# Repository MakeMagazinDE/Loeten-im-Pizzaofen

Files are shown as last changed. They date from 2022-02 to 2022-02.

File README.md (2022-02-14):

GitHub Logo

Maker Media GmbH

***

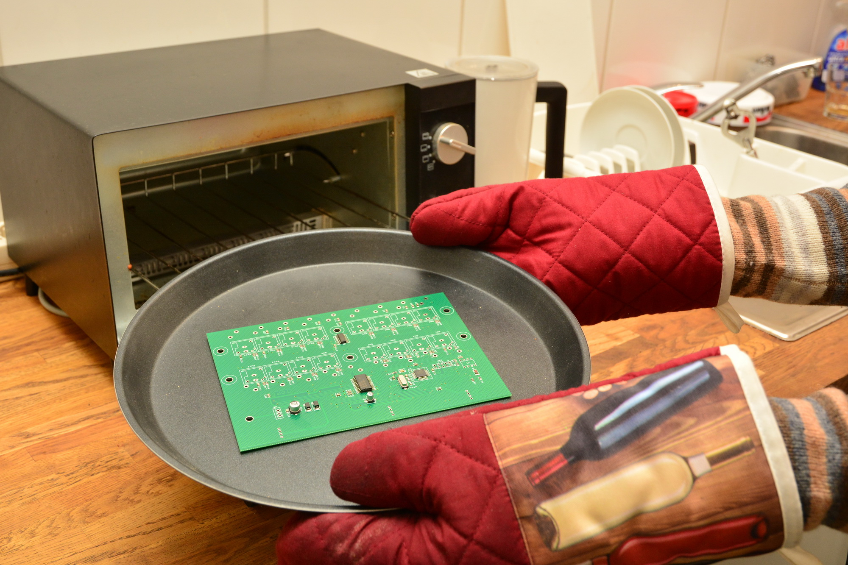
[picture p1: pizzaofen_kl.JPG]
 

# Löten im Pizzaofen

### Der Weg zur Platine, Teil 2

In unserem Artikel entsteht aus einem Pizza-Ofen eine praktische Reflow-Maschine für das Löten von SMD-Bauteilen mit WLAN-Fernsteuerung über den Browser.

**Nachtrag:** In der Schaltung ist R1 für normal helle LEDs zu hoch bemessen. Werte von 220 bis 470 Ohm sollten eine ausreichende Helligkeit erzielen.

### Verzeichnisse:

* **Beispielplatine** Die im Artikel angefertigte Platine, layoutet mit Sprint Layout (HPGL-Ausgabe)
* **reflow_oven** ESP32-Sourcen und Firmware
* **hpgl2gcode** Einfacher Konverter für HPGL-Dateien in G-Code, Sourcen und ausführbare EXE

Den vollständigen Artikel mit der Bauanleitung gibt es in der [Make-Ausgabe 1/22 ab Seite 86](https://www.heise.de/select/make/2022/1).

Teil 1 finden Sie in der [Make-Ausgabe 6/21 ab Seite 104](https://www.heise.de/select/make/2021/6/2130609051769976417).

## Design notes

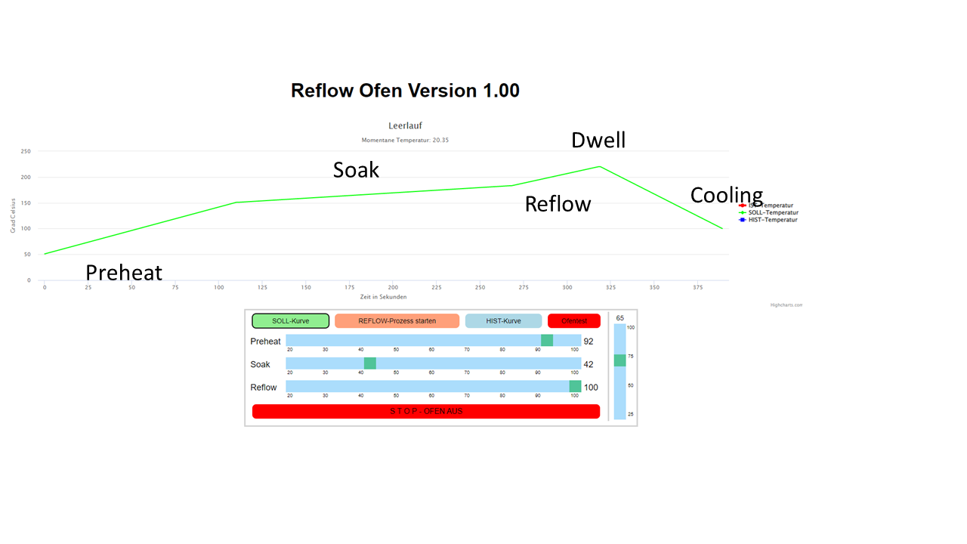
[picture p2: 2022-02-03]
reflow-profil.png

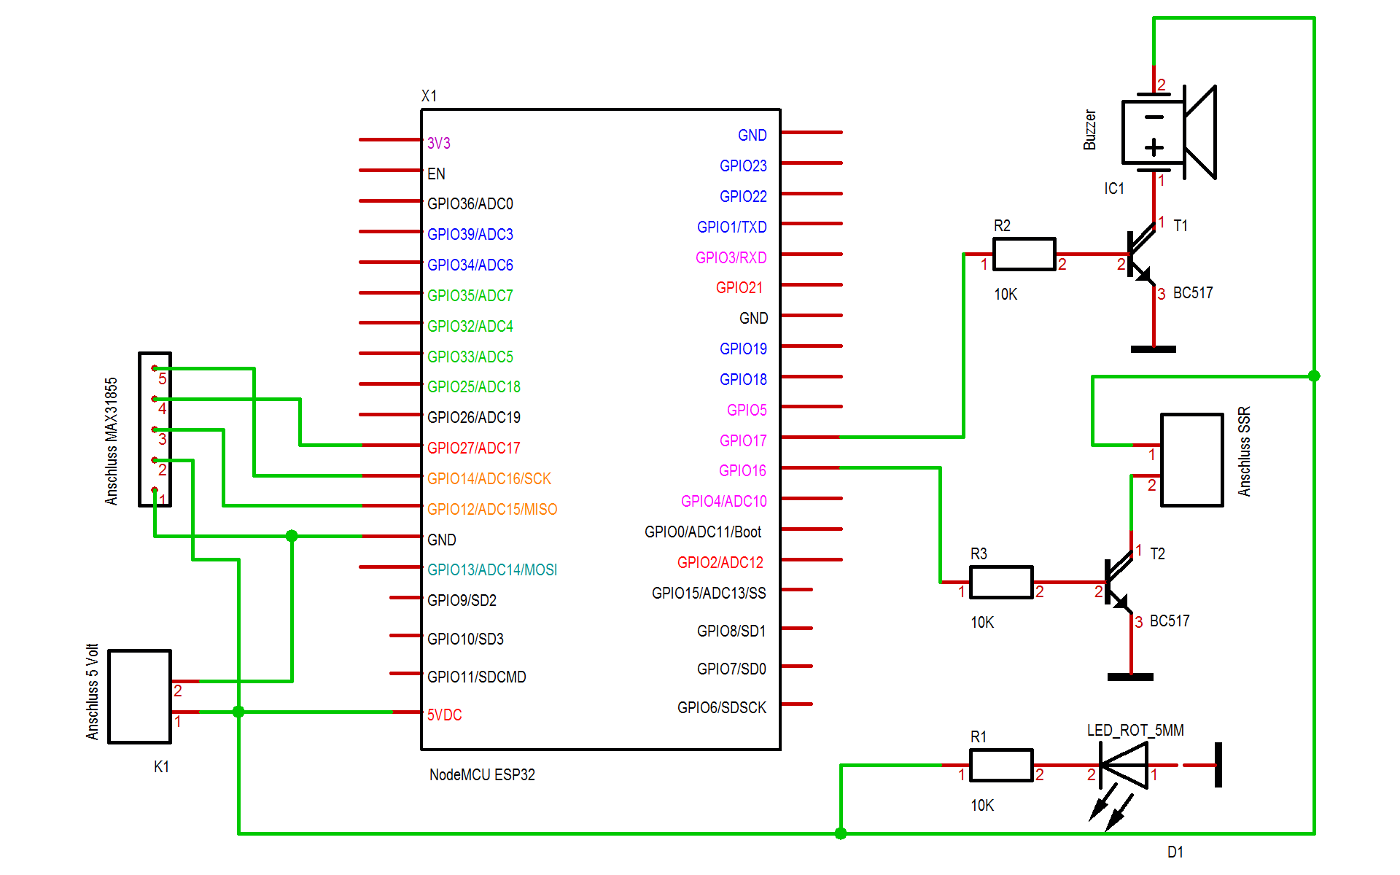
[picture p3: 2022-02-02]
Schaltung.png

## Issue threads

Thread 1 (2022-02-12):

Where is the source code?

markusrudolf, 2022-02-12:
Hi,
I assume you have article submission deadline 4 week before the print issue is released, so why is there no source yet?

I'm in desperate need of the source code since I just got my Pizza oven, was looking for some oven controller project for it when I got my Make Magazine in the mailbox and thought: "Perfect timing" and now learned there is no source for the project here yet. Very disappointing.

Can you please expedite the upload or PM me the "as-is" state?

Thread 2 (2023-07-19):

Inkompatibilität mit highcharts.js Version 11?

holzachr, 2023-07-19:
Die index.html enthält die Zeile
`<script src="https://code.highcharts.com/highcharts.js"></script>`
und verschiedene Browser zeigen mir keinen Graphen mehr an.
Das liegt vermutlich daran, dass genannter Weblink inzwischen zu Version 11 weiter entwickelt wurde, und das ursprüngliche Projekt mit Version 9 (oder 10) entwickelt wurde.
Mit
`<script src="https://code.highcharts.com/9/highcharts.js"></script>`
kann innerhalb der index.html auf eine spezifische Version der Library verwiesen werden.
Wäre es sogar möglich, die Library in Version 9/10 direkt mit der index.html auf den ESP32 zu verpacken?

holzachr, 2023-07-19:
`<script src="https://code.highcharts.com/10/highcharts.js"></script>`
funktioniert vorzüglich.

Die highcharts.js mit auf das Target zu packetieren funktioniert jedoch nicht. Ich könnte mir vorstellen, dass der ESP-Webserver nicht genügend RAM für den Upload der 300-KB-Datei hat.

Was allerdings, wenn highcharts.com irgendwann nicht mehr erreichbar ist? Es wäre sehr schade, wenn all unsere Reflow-Öfen dann unbenutzbar würden.

Vielleicht weiß jemand eine "richtige" Lösung für das Problem?

holzachr, 2023-07-19:
Doch, wenn man das richtig macht, dann funktioniert das auch.
PR folgt.

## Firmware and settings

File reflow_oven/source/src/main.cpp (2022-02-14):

/* ----------------------------------------------------------------------------
 * "THE BEER-WARE LICENSE" (Revision 42):
 * <gustavwostrack@web.de> wrote this file. As long as you retain this
 * notice you can do whatever you want with this stuff. If we meet some day,
 * and you think this stuff is worth it, you can buy me a beer in return
 * Gustav Wostrack
 * ----------------------------------------------------------------------------
 */

#include <Arduino.h>
// Import required libraries
#include <WiFi.h>
#include "ESPAsyncWebServer.h"
#include "SPIFFS.h"
#include <Wire.h>
#include "EEPROM.h"
#include "MAX31855.h"
#include <Ticker.h>
#include <WiFiAdr.h>

// Entferne den Kommentar, um weitere Infos auszugeben
//#define TESTPRINT

// Erste Version
const double Version = 1.00;

// Der Ofen kann im Reflow-Zustand sein oder nicht
typedef enum REFLOW_STATUS
{
  REFLOW_STATUS_OFF,
  REFLOW_STATUS_ON
} reflowStatus_t;

// Die folgenden Zustände werden in der Temperaturkurve durchlaufen
typedef enum TEMP_STATUS
{
  cold = 0, // Aufwärmen, unterhalb von BasisTemperatur
  preheat,  // von BasisTemperatur bis tempPreheatMax
  soak,     // von tempPreheatMax bis tempSoakMax
  reflow,   // von tempSoakMax bis tempReflowMax
  cooling,  // von tempReflowMax bis tempCoolMin
  complete  // unterhalb von tempCoolMin
} tempStatus_t;

// Diese Infos werden jede Sekunde im Verlauf gespeichert
struct sollTemperatureType
{
  double Temperature;
  TEMP_STATUS prePhase;
  TEMP_STATUS Phase;
  double preTemperature;
  uint8_t PWM;
};

// Anschluss des MAX31855
uint8_t const MAX31855_DO = GPIO_NUM_12;  // (12) MAX31855 data pin (HSPI MISO on ESP32)  - orange
uint8_t const MAX31855_CS = GPIO_NUM_27;  // (27) MAX31855 chip select pin                - red
uint8_t const MAX31855_CLK = GPIO_NUM_14; // (14) MAX31855 clock pin                      - brown
uint8_t const ssrPin = GPIO_NUM_16;
uint8_t const buzzerPin = GPIO_NUM_17;

// Create AsyncWebServer object on port 80
AsyncWebServer server(80);

// Initialize the Thermocouple
MAX31855 thermocouple(MAX31855_CLK, MAX31855_CS, MAX31855_DO);

// Damit der Buzzer Laut gibt
double const freqHi = 2000;
double const freqLo = 0;
uint8_t const channel = 0;
uint8_t const resolution = 8;
uint32_t const dutyCycle = 200;

// Einige  Variablen
uint16_t pwmOutput;
double currentTemperature;
uint16_t lastTemp = 0;
uint8_t preheatPWM, soakPWM, reflowPWM;
uint8_t preTimeFactor;

// Eckwerte der Temperaturkurve
const double BasisTemperatur = 50.0;
// Preheat
const double tempPreheatMax = 150.0;
const uint16_t preheatDuration = 120;
double preheatDelta = (tempPreheatMax - BasisTemperatur) / preheatDuration;
const uint16_t preheatFinishedTime = preheatDuration;
uint8_t overshootTimePreheat = 0;
// Soak
const double tempSoakMax = 183.0;
const uint16_t soakDuration = 180;
double soakDelta = (tempSoakMax - tempPreheatMax) / soakDuration;
const uint16_t soakFinishedTime = preheatFinishedTime + soakDuration;
uint8_t overshootTimeSoak = 0;
// Reflow
const double tempReflowMax = 220.0;
const uint16_t reflowDuration = 80;
const double reflowDelta = (tempReflowMax - tempSoakMax) / reflowDuration;
double tempReflowMin = 183.0;
const uint16_t reflowFinishedTime = soakFinishedTime + reflowDuration;
uint8_t overshootTimeReflow = 0;
// Cooling
const double tempCoolMin = 100.0;
const uint16_t coolingDuration = 90;
const uint16_t coolingFinishedTime = reflowFinishedTime + coolingDuration;
double coolingDelta = (tempCoolMin - tempReflowMax) / coolingDuration;

uint16_t timePreheatMaxPre, timeSoakMaxPre, timeReflowMaxPre;

const uint16_t ultimateSeconds = coolingFinishedTime;
sollTemperatureType sollTemperatur[ultimateSeconds];
uint16_t maxSeconds;
uint8_t curveTemperature[ultimateSeconds];

// EEPROM-Adressen (Non-Volatile Storage)
const uint8_t savedFlag = 0x47;
const uint16_t eepromAdrTemperatureFlag = lastAdr0 + adrFlag;
const uint16_t eepromAdrTemperature = eepromAdrTemperatureFlag + adrFlag;
const uint16_t eepromAdrParameterFlag = eepromAdrTemperature + sizeof(curveTemperature); // savedFlag
const uint16_t eepromAdrParameter0 = eepromAdrParameterFlag + adrFlag;                   // preheatPWM
const uint16_t eepromAdrParameter1 = eepromAdrParameter0 + sizeof(preheatPWM);           // soakPWM
const uint16_t eepromAdrParameter2 = eepromAdrParameter1 + sizeof(soakPWM);              // reflowPWM
const uint16_t eepromAdrParameter3 = eepromAdrParameter2 + sizeof(reflowPWM);            // overshootTimePreheat
const uint16_t eepromAdrParameter4 = eepromAdrParameter3 + sizeof(overshootTimePreheat);     // overshootTimeSoak
const uint16_t eepromAdrParameter5 = eepromAdrParameter4 + sizeof(overshootTimeSoak);        // overshootTimeReflow
const uint16_t eepromAdrParameter6 = eepromAdrParameter5 + sizeof(overshootTimeReflow);      // preTimeFactor
const uint16_t eepromAdrPasswordFlag = eepromAdrParameter6 + sizeof(preTimeFactor);
const uint16_t eepromAdrPassword = eepromAdrPasswordFlag + adrFlag;
const uint16_t eepromPWD = 0xFF;
const uint16_t EEPROM_SIZE = eepromAdrPassword + eepromPWD;

// Weitere Variablen
uint16_t secondsSOLL;
uint16_t secondsIST;
unsigned long windowStartTime;
tempStatus_t reflowState;    // Reflow oven controller state machine state variable
reflowStatus_t reflowStatus; // Reflow oven controller status
Ticker SSRtckr;
Ticker TSTtckr;
const uint32_t SSRtckrTime = 1;
const uint32_t TSTtckrTime = 1000;
const uint16_t minOutput = 0;
const uint16_t maxOutput = 100;

/////////////////// HELPER ///////////////////////
// Gibt Laut
void makeBeep()
{
  ledcWriteTone(channel, freqHi);
  delay(100);
  ledcWriteTone(channel, freqLo);
}
// Liest 5mal die Temperatur ein und ermittelt deren Durchschnitt.
// Dadurch werden Ausreißer vermieden.
double readTemperature()
{
  static double temp = 20.0;
  const uint8_t singleTemps = 5;
  static double temps[singleTemps] = {16.0f, 17.0f, 18.0f, 19.0f, 20.0f}; // Array for moving average filter

  thermocouple.read();

  if (thermocouple.getStatus())
  {
    Serial.print("FEHLER:\t\t");
    if (thermocouple.shortToGND())
      Serial.println("SHORT TO GROUND");
    if (thermocouple.shortToVCC())
      Serial.println("SHORT TO VCC");
    if (thermocouple.openCircuit())
      Serial.println("OPEN CIRCUIT");
    if (thermocouple.genericError())
      Serial.println("GENERIC ERROR");
    if (thermocouple.noRead())
      Serial.println("NO READ");
    if (thermocouple.noCommunication())
      Serial.println("NO COMMUNICATION");
    return 0.0;
  }

  temps[0] = thermocouple.getTemperature();

  temp = (temps[0] + temps[1] + temps[2] + temps[3] + temps[4]) / 5.0f; // Compute average of last 5 readings
  temps[4] = temps[3];                                                  // Update moving average filter
  temps[3] = temps[2];
  temps[2] = temps[1];
  temps[1] = temps[0];
  return temp;
}
// Schaltet das Solid State Relay ein
void ovenON()
{
  digitalWrite(ssrPin, HIGH);
}
// Schaltet das Solid State Relay (SSR) aus
void ovenOFF()
{
  digitalWrite(ssrPin, LOW);
}
// Setzt die Frequenz der Pulsweitenmodulation,
// mit der das SSR beaufschlagt wird.
void setPWM(uint16_t pwm)
{
  pwmOutput = pwm;
}
// Liest die Frequenz der PWM aus
uint16_t getPWM()
{
  return pwmOutput;
}
// Schaltet den Ofen entweder vollständig ein (MaxOutput)
// oder im Rythmus der PWM
// Diese Prozedur wird jede Millisekunden vom Timer SSRtckr aufgerufen
// Wurde PWM beispielsweise auf 60 gesetzt, dann ist der Ofen
// 60 Millisekunden ein- und 40 Millisekunden ausgeschaltet.
// Darüber hinaus wird die LED im Sekundenrythmus ein- und ausgeschaltet. 
void setSSR()
{
  static bool onOff = true;
  static uint16_t blinkCntr = 0;
  if (reflowStatus == REFLOW_STATUS_ON)
  {
    if (getPWM() == maxOutput)
    {
      ovenON();
    }
    else
    {
      blinkCntr++;
      if (blinkCntr >= (1000 / SSRtckrTime))
      {
        blinkCntr = 0;
        onOff = !onOff;
      }
      digitalWrite(BUILTIN_LED, onOff);
      static uint16_t elapsedTime = 0;
      elapsedTime++;
      if (getPWM() >= elapsedTime)
        ovenON();
      else
        ovenOFF();
      if (elapsedTime >= maxOutput)
        elapsedTime = 0;
    }
  }
  else
    ovenOFF();
}
// Weiterer Ofeneinschalter
void switchOvenOFF()
{
  reflowStatus = REFLOW_STATUS_OFF;
  ovenOFF();
  setPWM(minOutput);
}
// Weiterer Ofenausschalter
void switchOvenON()
{
  reflowStatus = REFLOW_STATUS_ON;
  ovenON();
  setPWM(maxOutput);
}
// Diese Prozedur durchläuft einen vollständigen Temperaturzyklus.
// Immer wenn die Temperatur in eine neue Phase eintritt,
// wird der Ofen ausgeschaltet und die Zeit gemessen,
// bis die Temperatur nicht weiter steigt. Damit werden die Überschwinger
// ermittelt. Darüber hinaus wird berechnet, welche Zeit benötigt wird, um eine
// Phase zu durchlaufen. Diese Daten bilden dann die Ausgangswerte
// für den Reflowprozess.
void ofenTESTProc()
{
  double currentTemp = 0;
  static double lastTemperature = 0;
  static double lastBeforeTemperature = 0;
  const uint8_t finishPhase = 11;
  static uint8_t phase = 0;
  static uint16_t runningTime = 0;
  static uint16_t inTime;
  static uint16_t overshootInTime = 0;;
  static double deltaPreheat = 0;
  static double deltaSoak = 0;
  static double deltaReflow = 0;
  /*
  phase0: unterhalb roomtemp
  phase1: zwischen roomtemp und preheatmax
  phase2: overshoot preheat
  phase3: warten auf preheatmax
  phase4: zwischen  preheatmax und soakmax
  phase5: overshoot soak
  phase6: warten auf soak
  phase7: zwischen  soakmax und reflowkmax
  phase8: overshoot reflow
  phase9: finish

  const double BasisTemperatur = 30.0;
  const double tempPreheatMax = 150.0;
  const double tempSoakMax = 183.0;
  const double tempReflowMax = 230.0;
  double tempReflowMin = 183.0;
  const double tempCoolMin = 100.0;
  */
  currentTemp = readTemperature();
  Serial.println("Temperatur: " + String(currentTemp));
  switch (phase)
  {
  case 0:
    // schaltet Ofen ein und
    // heizt auf bis BasisTemperatur erreicht ist
    // dann nächste Phase
    if (runningTime == 0)
    {
      // Ofen einschalten
      reflowStatus = REFLOW_STATUS_ON;
      ovenON();
      setPWM(maxOutput);
    }
    if (currentTemp >= BasisTemperatur)
    {
      phase = 1;
      inTime = runningTime;
    }
    break;
  case 1:
    // heizt auf bis tempPreheatMax erreicht ist
    // schaltet dann Ofen aus und nächste Phase
    if (currentTemp >= tempPreheatMax)
    {
      // Ofen ausschalten
      switchOvenOFF();
      deltaPreheat = (tempPreheatMax - BasisTemperatur) / (runningTime - inTime);
      overshootInTime = runningTime;
      phase = 2;
    }
    break;
  case 2:
    // wartet bis der overshoot sinkt
    if ((currentTemp < lastTemperature) && (lastTemperature < lastBeforeTemperature))
    {
      overshootTimePreheat = runningTime - overshootInTime;
      phase = 3;
    }
    break;
  case 3:
    // wartet bis tempPreheatMax wieder erreicht ist
    // und schaltet den Ofen wieder ein, nächste Phase
    if (currentTemp <= tempPreheatMax)
    {
      // Ofen einschalten
      switchOvenON();
      phase = 4;
    }
    break;
  case 4:
    // hier beginnt die soak-Phase
    if (currentTemp >= tempPreheatMax)
    {
      inTime = runningTime;
      phase = 5;
    }
    break;
  case 5:
    // heizt auf bis tempSoakMax erreicht ist
    // schaltet dann Ofen aus und nächste Phase
    if (currentTemp >= tempSoakMax)
    {
      // Ofen ausschalten
      switchOvenOFF();
      deltaSoak = (tempSoakMax - tempPreheatMax) / (runningTime - inTime);
      lastTemperature = currentTemp;
      overshootInTime = runningTime;
      phase = 6;
    }
    break;
  case 6:
    // wartet bis der overshoot sinkt
    if ((currentTemp < lastTemperature) && (lastTemperature < lastBeforeTemperature))
    {
      overshootTimeSoak = runningTime - overshootInTime;
      phase = 7;
    }
    break;
  case 7:
    // wartet bis tempSoakMax wieder erreicht ist
    // und schaltet den Ofen wieder ein, nächste Phase
    if (currentTemp <= tempSoakMax)
    {
      // Ofen einschalten
      switchOvenON();
      phase = 8;
    }
    break;
  case 8:
    // hier beinnt die reflow-Phase
    if (currentTemp >= tempSoakMax)
    {
      inTime = runningTime;
      phase = 9;
    }
    break;
  case 9:
    // heizt auf bis tempReflowMax erreicht ist
    // schaltet dann Ofen aus und nächste Phase
    if (currentTemp >= tempReflowMax)
    {
      // Ofen ausschalten
      switchOvenOFF();
      deltaReflow = (tempReflowMax - tempSoakMax) / (runningTime - inTime);
      lastTemperature = currentTemp;
      overshootInTime = runningTime;
      phase = 10;
    }
    break;
  case 10:
    // wartet bis der overshoot sinkt
    if ((currentTemp < lastTemperature) && (lastTemperature < lastBeforeTemperature))
    {
      overshootTimeReflow = runningTime - overshootInTime;
      phase = 11;
    }
    break;
  case finishPhase:
    // fertig
    // Erfebnisse speichern
    TSTtckr.detach(); // each sec

    // speichern der Ergebnisse
    // preheat
    preheatPWM = preheatDelta / deltaPreheat * maxOutput;
    EEPROM.writeByte(eepromAdrParameter0, preheatPWM);
    EEPROM.commit();
    EEPROM.writeByte(eepromAdrParameter3, overshootTimePreheat);
    EEPROM.commit();
#ifdef TESTPRINT
    Serial.println("overshootTimePreheat: " + String(overshootTimePreheat));
    Serial.println("preheatDelta: " + String(preheatDelta) + " - deltaPreheat: " + String(deltaPreheat) + " - " + String(preheatPWM));
#endif
    // soak
    soakPWM = soakDelta / deltaSoak * maxOutput;
    EEPROM.writeByte(eepromAdrParameter1, soakPWM);
    EEPROM.commit();
    EEPROM.writeByte(eepromAdrParameter4, overshootTimeSoak);
    EEPROM.commit();
#ifdef TESTPRINT
    Serial.println("overshootTimeSoak: " + String(overshootTimeSoak));
    Serial.println("soakDelta: " + String(soakDelta) + " - deltaSoak: " + String(deltaSoak) + " - " + String(soakPWM));
#endif
    // reflow
    reflowPWM = reflowDelta / deltaReflow * maxOutput;
    EEPROM.writeByte(eepromAdrParameter2, reflowPWM);
    EEPROM.commit();
    EEPROM.writeByte(eepromAdrParameter5, overshootTimeReflow);
    EEPROM.commit();
#ifdef TESTPRINT
    Serial.println("overshootTimeReflow: " + String(overshootTimeReflow));
    Serial.println("reflowDelta: " + String(reflowDelta) + " - deltaReflow: " + String(deltaReflow) + " - " + String(reflowPWM));
#endif
    EEPROM.writeByte(eepromAdrParameterFlag, savedFlag);
    EEPROM.commit();

    break;
  default:
    break;
  }
  runningTime++;
  lastBeforeTemperature = lastTemperature;
  lastTemperature = currentTemp;
  Serial.println("TEST laeuft in Phase: " + String(phase) + " nach Sekunden: " + String(runningTime));
  return;
}
// Diese Prozedur wird vom Browser gestartet. Sie initialisiert den Timer TSTtckr,
// der wiederum die Prozedur ofenTESTProc jede Sekunde (alle 1000 Millisekunden)
// aufruft.
String ofenTEST()
{
  TSTtckr.attach_ms(TSTtckrTime, ofenTESTProc); // each sec
  return "1";
}
// Die Prozedur getNextSollTemp ist eine Hilfsprozdur für die
// eigentliche Festlegung der Solltemperaturkurve in der Prozedur defineSOLLTemp.
// Sie errechnet aus der momentanen Temperatur priorTemp und der Temperatursteigungsrate
// die Rückgabetemperatur bis die Maxomaltemperatur max der jeweiligen Phase erreicht ist. 
double getNextSollTemp(double priorTemp, double max, double delta)
{
  double nextTemp = priorTemp;
  if (delta > 0)
  {
    if (priorTemp < max)
      nextTemp = priorTemp + delta;
  }
  else
  {
    if (priorTemp > max)
      nextTemp = priorTemp + delta;
  }
  return nextTemp;
}
// In dieser Prozedur wird die Solltemperatur für eine bestimmte Sekunde
// festgelegt und in das Array sollTemperatur geschrieben.
void defineSOLLTemp(uint16_t second)
{
  static double temperature;
  static double nextTemp = BasisTemperatur;

  temperature = nextTemp;
  switch (reflowState) // Reflow oven controller state machine
  {

  case preheat:                        // If state = PREHEAT
    if (temperature >= tempPreheatMax) // If minimum soak temperature is achieved
    {
      reflowState = soak; // Proceed to soaking state
    }
    else
      nextTemp = getNextSollTemp(nextTemp, tempPreheatMax, preheatDelta);
    break;

  case soak:                        // If state = SOAK
    if (temperature >= tempSoakMax) // If maximum soak temperature is achieved
    {
      reflowState = reflow; // Proceed to reflowing state
    }
    else
      nextTemp = getNextSollTemp(nextTemp, tempSoakMax, soakDelta);
    break;

  case reflow:                        // If state = REFLOW HEAT
    if (temperature >= tempReflowMax) // If maximum reflow temperature is achieved
    {
      reflowState = cooling; // Proceed to reflowing level state
    }
    else
      nextTemp = getNextSollTemp(nextTemp, tempReflowMax, reflowDelta);
    break;

  case cooling:                     // If state = REFLOW COOL
    if (temperature <= tempCoolMin) // If minimummum reflow temperature is achieved
    {
      nextTemp = BasisTemperatur - 1; // 
      reflowState = complete;          // Proceed to cool down state
    }
    else
      nextTemp = getNextSollTemp(nextTemp, tempCoolMin, coolingDelta);
    break;
  case cold:
  case complete: // If state = REFLOW COOL DOWN
    break;
  }
  sollTemperatur[second].Temperature = nextTemp;
  sollTemperatur[second].prePhase = reflowState;
  sollTemperatur[second].Phase = reflowState;
  sollTemperatur[second].preTemperature = nextTemp;
  switch (reflowState)
  {
  case preheat:
    sollTemperatur[second].PWM = preheatPWM;
    break;
  case soak:
    sollTemperatur[second].PWM = soakPWM;
    break;
  case reflow:
    sollTemperatur[second].PWM = reflowPWM;
    break;
  case cold:
  case cooling:
  case complete:
    sollTemperatur[second].PWM = minOutput;
    break;
  }
}
// Um dem Überschwingen zu begegnen, werden die Paramater der nächsten Phase
// etwas früher angewandet. Mit Hilfe der Daten aus der Prozedur Ofentest werden
// die Zeiten hier berechnet.
void calcPreValues()
{
  // Zeiten, vor denen denen bereits die PWM-Werte der nächsten Phase eingestellt werden
  timePreheatMaxPre = (overshootTimePreheat * preTimeFactor) / maxOutput;
  timeSoakMaxPre = (overshootTimeSoak * preTimeFactor) / maxOutput;
  timeReflowMaxPre = (overshootTimeReflow * preTimeFactor) / maxOutput / 4;
#ifdef TESTPRINT
  Serial.println("timePreheatMaxPre: "+String(timePreheatMaxPre));
  Serial.println("timeSoakMaxPre: "+String(timeSoakMaxPre));
  Serial.println("timeReflowMaxPre: "+String(timeReflowMaxPre));
  Serial.println("preheatPWM: "+String(preheatPWM));
  Serial.println("soakPWM: "+String(soakPWM));
  Serial.println("reflowPWM: "+String(reflowPWM));
  Serial.println("preTimeFactor: "+String(preTimeFactor));
#endif
}
// Die durch calcPreValues veränderten Werte werden in das sollTemperatur-Array
// eingearbeitet
void rebuildPreTempArray()
{
  calcPreValues();
  // soak zum Ende von preheat vorziehen
  for (uint16_t p = 0; p < timePreheatMaxPre; p++)
  {
    sollTemperatur[preheatFinishedTime - p].prePhase = sollTemperatur[preheatFinishedTime + timePreheatMaxPre - p].prePhase;
    sollTemperatur[preheatFinishedTime - p].PWM = sollTemperatur[preheatFinishedTime + timePreheatMaxPre - p].PWM;
  }
  // reflow zum Ende von soak vorziehen
  for (uint16_t s = 0; s < timeSoakMaxPre; s++)
  {
    sollTemperatur[soakFinishedTime - s].prePhase = sollTemperatur[soakFinishedTime + timeSoakMaxPre - s].prePhase;
    sollTemperatur[soakFinishedTime - s].PWM = sollTemperatur[soakFinishedTime + timeSoakMaxPre - s].PWM;
  }
  // cooling zum Ende von reflow vorziehen
  for (uint16_t r = 0; r < timeReflowMaxPre; r++)
  {
    // reflowFinishedTime = 380 - timeReflowMaxPre = 9
  //  sollTemperatur[reflowFinishedTime - r].preTemperature = sollTemperatur[reflowFinishedTime + timeReflowMaxPre - r].preTemperature;
    sollTemperatur[reflowFinishedTime - r].prePhase = sollTemperatur[reflowFinishedTime + timeReflowMaxPre - r].prePhase;
    sollTemperatur[reflowFinishedTime - r].PWM = sollTemperatur[reflowFinishedTime + timeReflowMaxPre - r].PWM;
  }
}
// Während die Prozedur defineSOLLTemp die Solltemperatur für eine bestimmte
// Sekunde festlegt, wird hier der gesamte Temperaturverlauf abgearbeitet.
void setDataSOLL()
{
  reflowState = preheat;
  for (maxSeconds = 0; maxSeconds < ultimateSeconds; maxSeconds++)
  {
    defineSOLLTemp(maxSeconds); // mindestens 1 mal in der Sekunde
    if (sollTemperatur[maxSeconds].Temperature < BasisTemperatur)
    {
      digitalWrite(BUILTIN_LED, HIGH);
      break;
    }
  }
  rebuildPreTempArray();
#ifdef TESTPRINT
  for (uint16_t sec = 0; sec < maxSeconds; sec++)
  {
    Serial.print(String(sec));
    Serial.print(" - Temp: " + String(sollTemperatur[sec].Temperature));
    Serial.print(" - prePhase: " + String(sollTemperatur[sec].prePhase));
    Serial.print(" - preTemperature: " + String(sollTemperatur[sec].preTemperature));
    Serial.println(" - PWM: " + String(sollTemperatur[sec].PWM));
  }
#endif
}
// Diese Funktion wird von der Browseranwendung direkt zu Beginn aufgeruen und
// gibt zurück, die Gesamtzeit eines Temperaturverlaufes, sowie die PWM-Werte der
// einzelnen Phasen.
String maxTime()
{
  return String(maxSeconds) + "/" + String(preheatPWM) + "/" + String(soakPWM) + "/" + String(reflowPWM) + "/" + String(preTimeFactor);
}
// Nach einem Reflowprozess wird der tatsächliche Verlauf gespeichert
// und kann später wieder abgerufen werden.
void saveTemperature()
{
  if (lastTemp == 0)
    return;
  curveTemperature[lastTemp] = 0x00;
  // Flag setzen, dass eine Temperaturkurve gespeichert wurde
  EEPROM.writeByte(eepromAdrTemperatureFlag, savedFlag);
  EEPROM.commit();
  // Temperatur sichern
  for (uint16_t x = 0; x < lastTemp + 1; x++)
  {
    EEPROM.writeByte(eepromAdrTemperature + x, curveTemperature[x]);
    Serial.println(curveTemperature[x]);
    EEPROM.commit();
  }
  lastTemp = 0;
}
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
void loop()
{
  saveTemperature();
}

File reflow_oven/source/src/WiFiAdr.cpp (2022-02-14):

/* ----------------------------------------------------------------------------
 * "THE BEER-WARE LICENSE" (Revision 42):
 * <gustavwostrack@web.de> wrote this file. As long as you retain this
 * notice you can do whatever you want with this stuff. If we meet some day,
 * and you think this stuff is worth it, you can buy me a beer in return
 * Gustav Wostrack
 * ----------------------------------------------------------------------------
 */

#include <Arduino.h>
#include "WiFiAdr.h"
#include <WiFi.h>
#include "esp_timer.h"
#include "ticker.h"
#include "EEPROM.h"

// EEPROM-Adressen
const uint16_t eepromAdr = 0x00;
const uint8_t eepromChr = 0xFF;
uint16_t adrMax = 0x1000;

Ticker blinkTckr;
const float tckrTime = 0.01;

enum blinkStatus
{
  blinkFast = 0, // wartet auf Password
  blinkSlow,     // wartet auf WiFi
  blinkNo        // mit WiFi verbunden
};
blinkStatus blink;

uint8_t setup_todo;

void get_EEPROM_SIZE(uint16_t SIZE)
{
  adrMax = SIZE;
}
// Liest das Passwort über das Terminalprogramm
String liesEingabe()
{
  boolean newData = false;
  char receivedChars[numChars]; // das Array für die empfangenen Daten
  static byte ndx = 0;
  char endMarker = '\r';
  char rc;

  while (newData == false)
  {
    while (Serial.available() > 0)
    {
      rc = Serial.read();

      if (rc != endMarker)
      {
        receivedChars[ndx] = rc;
        Serial.print(rc);
        ndx++;
        if (ndx >= numChars)
        {
          ndx = numChars - 1;
        }
      }
      else
      {
        receivedChars[ndx] = '\0'; // Beendet den String
        Serial.println();
        ndx = 0;
        newData = true;
      }
    }
  }
  return receivedChars;
}
// Scannt das heimische Netzwerk und zeigt alle möglichen WLAN an
String netzwerkScan()
{
  // Zunächst Station Mode und Trennung von einem AccessPoint, falls dort eine Verbindung bestand
  WiFi.mode(WIFI_STA);
  WiFi.disconnect();
  delay(100);

  Serial.println("Scan-Vorgang gestartet");

  // WiFi.scanNetworks will return the number of networks found
  int n = WiFi.scanNetworks();
  Serial.println("Scan-Vorgang beendet");
  if (n == 0)
  {
    Serial.println("Keine Netzwerke gefunden!");
  }
  else
  {
    Serial.print(n);
    Serial.println(" Netzwerke gefunden");
    for (int i = 0; i < n; ++i)
    {
      // Drucke SSID and RSSI für jedes gefundene Netzwerk
      Serial.print(i + 1);
      Serial.print(": ");
      Serial.print(WiFi.SSID(i));
      Serial.print(" (");
      Serial.print(WiFi.RSSI(i));
      Serial.print(")");
      Serial.println((WiFi.encryptionType(i) == WIFI_AUTH_OPEN) ? " " : "*");
      delay(10);
    }
  }
  uint8_t number;
  do
  {
    Serial.println("Bitte Netzwerk auswaehlen: ");
    String no = liesEingabe();
    number = uint8_t(no[0]) - uint8_t('0');
  } while ((number > n) || (number == 0));

  return WiFi.SSID(number - 1);
}

// der Timer steuert da Blinken der LED
void timer1s()
{
  static uint8_t secs = 0;
  static uint8_t slices = 0;
  slices++;
  switch (blink)
  {
  case blinkFast:
    if (slices >= 10)
    {
      slices = 0;
      secs++;
    }
    break;
  case blinkSlow:
    if (slices >= 40)
    {
      slices = 0;
      secs++;
    }
    break;
  case blinkNo:
    secs = 2;
    break;
  }
  if (secs % 2 == 0)
    // turn the LED on by making the voltage HIGH
    digitalWrite(BUILTIN_LED, HIGH);
  else
    // turn the LED off by making the voltage LOW
    digitalWrite(BUILTIN_LED, LOW);
}
// Bei Bedarf wird der nicht flüchtige Speicher (EEPROM) gelöscht
void eraseEEPROM()
{
  Serial.println("Bitte warten!");
  for (uint16_t adr = 0; adr < adrMax; adr++)
    EEPROM.write(eepromAdr + adr, eepromChr);
  EEPROM.commit();
  // setup in der Anwndung erzwingen
  setup_todo = setup_NOT_done;
  Serial.println("EEPROM erfolgreich geloescht!");
}
// Falls ein Passwort bereits eingegeben wurde, wird versucht damit an das
// zugehörige WLAN zu koppeln. Andernfalls wird aufgefordert, ein WLAN auszusuchen
// und das zugehörige Passwort einzugeben.
// Die kommunikation läuft über den USB-Anschluss bzw. ein verbundenes Terminal-
// programm
void Connect2WiFi()
{
  blinkTckr.attach(tckrTime, timer1s); // each sec
  blink = blinkFast;
  String ssid = "";
  String password = "";
  setup_todo = EEPROM.readByte(adr_setup_done);
  if (setup_todo != setup_done)
  {
    String answer;
    do
    {
      Serial.println("EEPROM loeschen (J/N)?: ");
      answer = liesEingabe();
      answer.toUpperCase();
    } while ((answer != "J") && (answer != "N"));
    if (answer == "J")
      eraseEEPROM();
    else
    {
      answer = "";
      do
      {
        Serial.println("Neue Netzwerkdaten (J/N)?: ");
        answer = liesEingabe();
        answer.toUpperCase();
      } while ((answer != "J") && (answer != "N"));
    }
    if (answer == "J")
    {
      // alles fürs erste Mal
      //
      ssid = netzwerkScan();
      EEPROM.writeString(adr_ssid, ssid);
      EEPROM.commit();
      Serial.println();
      // liest das password ein
      Serial.println("Bitte das Passwort eingeben: ");
      Serial.print("(Falls Sie sich dabei vertippen, muessen Sie den Prozess neu starten!!): ");
      password = liesEingabe();
      EEPROM.writeString(adr_password, password);
      EEPROM.commit();
      Serial.println();
    }
  }
  else
  {
    Serial.println("Zur Neueingabe der Anmeldedaten beliebige Taste druecken!");
    delay(5000);
    if (Serial.available() > 0)
    {
      // zuviele Versuche für diese Runde
      EEPROM.writeByte(adr_setup_done, setup_NOT_done);
      EEPROM.commit();
      ESP.restart();
    }
    blink = blinkSlow;
    ssid = EEPROM.readString(adr_ssid);
    password = EEPROM.readString(adr_password);
  }
  char ssidCh[ssid.length() + 1];
  ssid.toCharArray(ssidCh, ssid.length() + 1);
  char passwordCh[password.length() + 1];
  password.toCharArray(passwordCh, password.length() + 1);
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
